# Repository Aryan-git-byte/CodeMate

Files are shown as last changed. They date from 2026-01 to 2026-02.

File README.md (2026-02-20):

# CodeMate - My Dev Macropad
hiii! this is my hackpad submission. built a 3x3 macropad to speed up my coding workflow

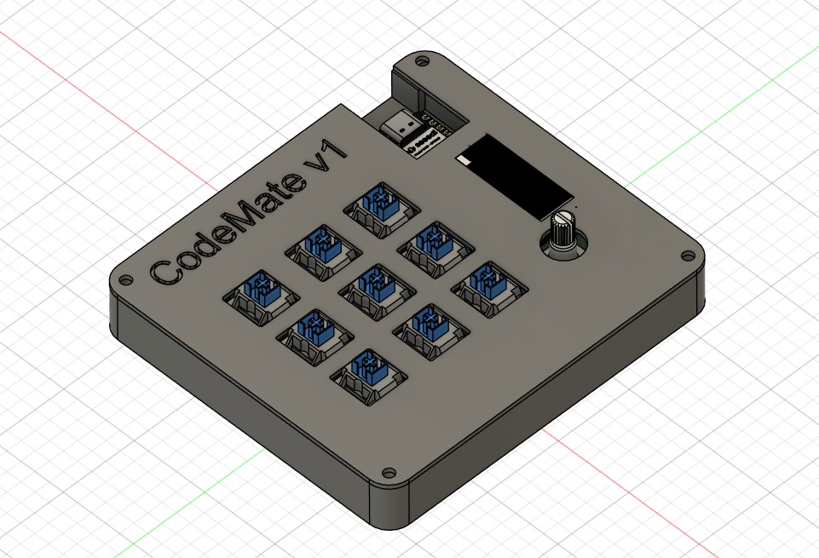
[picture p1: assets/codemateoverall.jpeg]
CodeMate Overall


## what it does
- 9 mechanical switches in a 3x3 grid for shortcuts and macros
- rotary encoder for volume control
- 0.91" OLED that shows which key i just pressed (flashes for 1.5sec then shows "ready")
- 6 RGB LEDs that breathe in warm amber and pulse when i hit keys
- runs on Arduino (not KMK anymore) so i can use TinyUSB

## PCB
heres what the electronics look like:

| Schematic | PCB |
|---|-----|
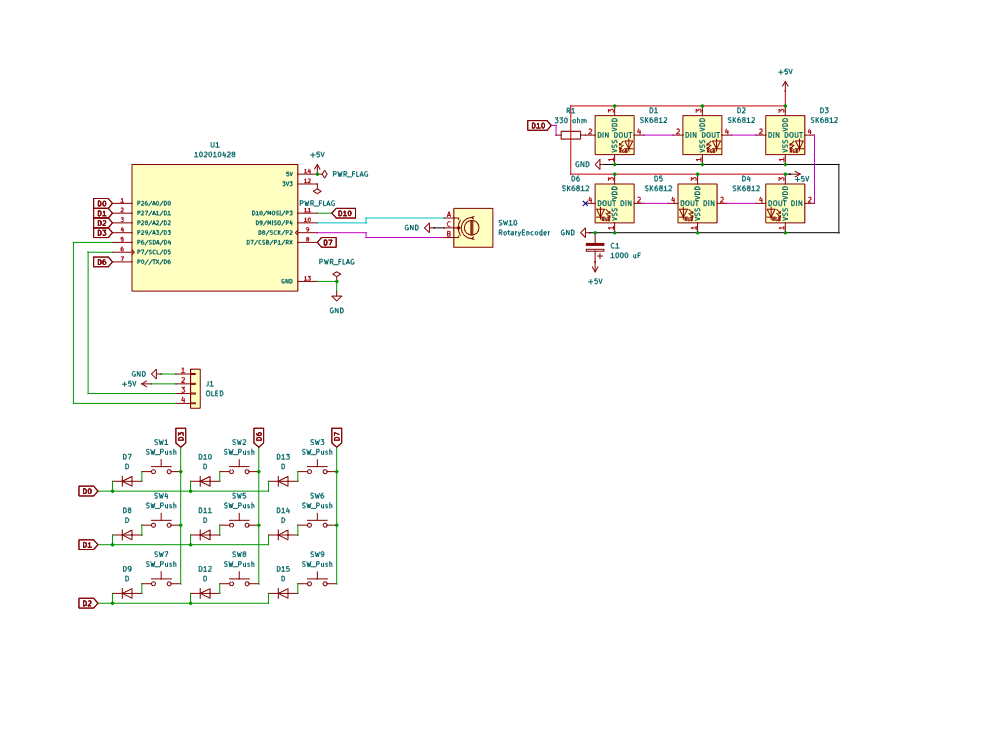
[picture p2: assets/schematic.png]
Schematic
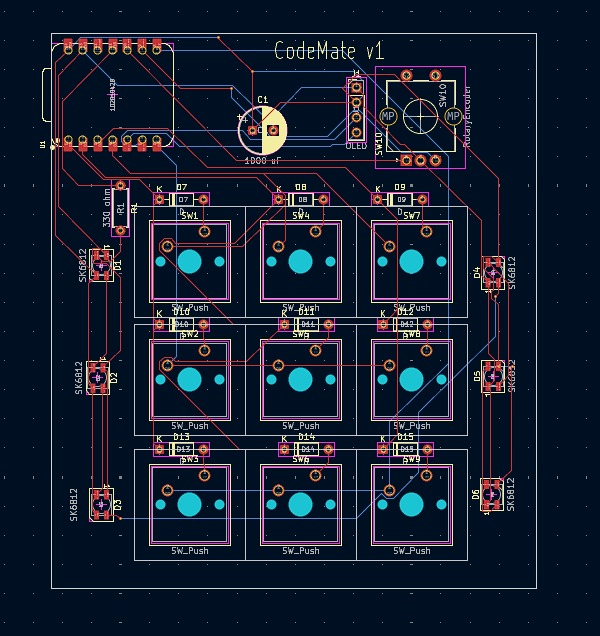
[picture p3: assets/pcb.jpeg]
PCB
|  |  |

took me a few tries to get the routing right but it works now

[x] I ran DRC and there are 0 errors but few silkscreen warnings

## Case
made in fusion360. fits everything together with M3 screws and heatset inserts

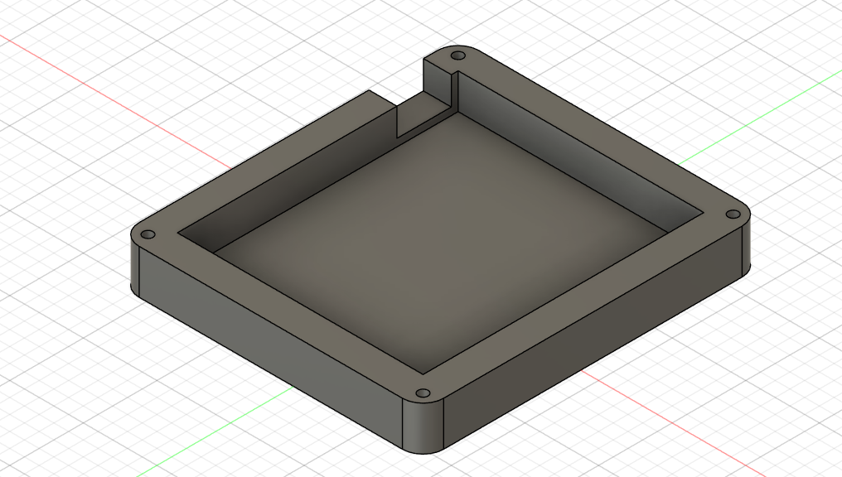
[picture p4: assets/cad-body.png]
CAD Model


along with the top:

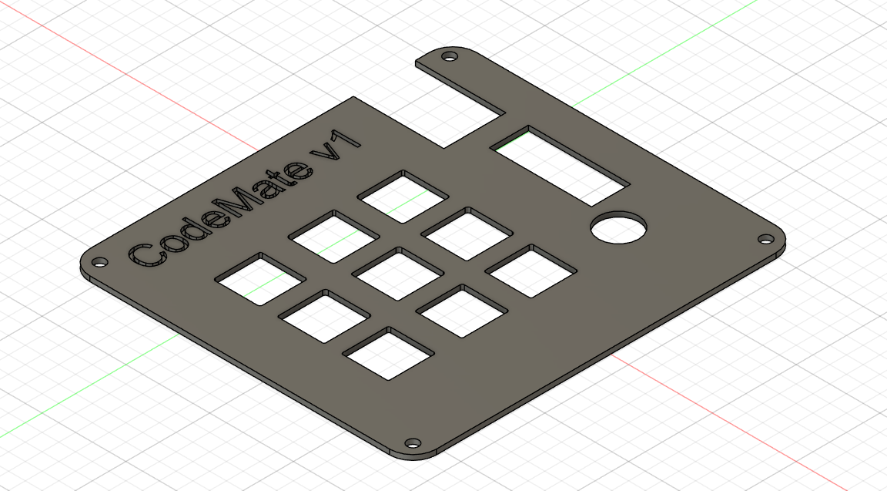
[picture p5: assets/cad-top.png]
CAD-Top


the switches poke through the top plate and the oled sits in a cutout. pretty clean imo

## Firmware
rewrote it in Arduino because i wanted better HID support. NO LAYERS anymore, just 9 coding shortcuts that i actually use:

**The Layout:**
```
Comment      | Format Code    | Duplicate Line
Run (F5)     | Terminal       | Close Tab
git status   | git commit     | git push
```

Encoder: Volume up/down (stays the same always)

### what each key does
- **Key 0:** Toggle comment (Ctrl+/)
- **Key 1:** Format code (Shift+Alt+F)
- **Key 2:** Duplicate line (Shift+Alt+Down)
- **Key 3:** Run code (F5)
- **Key 4:** Toggle terminal (Ctrl+`)
- **Key 5:** Close tab (Ctrl+W)
- **Key 6:** Opens terminal + runs `git status`
- **Key 7:** Opens terminal + types `git commit -m ""` with cursor inside quotes
- **Key 8:** Opens terminal + runs `git push`

git commands automatically open the VS Code terminal first (Ctrl+Shift+`) then type the command. super handy

### LED behavior
- **Normal:** slow breathing effect (10% to 40% brightness) in warm amber
- **When you press a key:** the LED near that key flashes bright then fades back to breathing
- **Color:** warm amber (255, 140, 0) because one of my LEDs has a dead blue channel lol

the oled shows which key i pressed for 1.5 seconds then goes back to showing "ready"

[x] no api keys or passwords in the code

## BOM
what you need to build this:
- 1x XIAO RP2040
- 9x Cherry MX switches  
- 9x 1N4148 diodes
- 6x SK6812 MINI-E LEDs (NOT WS2812B, different color order)
- 1x 0.91" SSD1306 OLED (128x32, I2C)
- 1x EC11 rotary encoder
- 1x 330Ω resistor (for LED data line - optional but recommended)
- 1x 1000µF capacitor (bulk cap for LEDs - optional but recommended)
- 4x M3x16mm screws
- 4x M3x5mmx4mm heatset inserts

## notes
this was fun to make! spent way too much time tweaking the firmware but learned a lot about Arduino HID and how SK6812 LEDs work differently from WS2812B.

switched from KMK to Arduino because i wanted proper keyboard+consumer HID support and the encoder was being weird in KMK. plus now i can do the breathing LED effect which looks way cooler than static colors

GG

# this is the prototype:

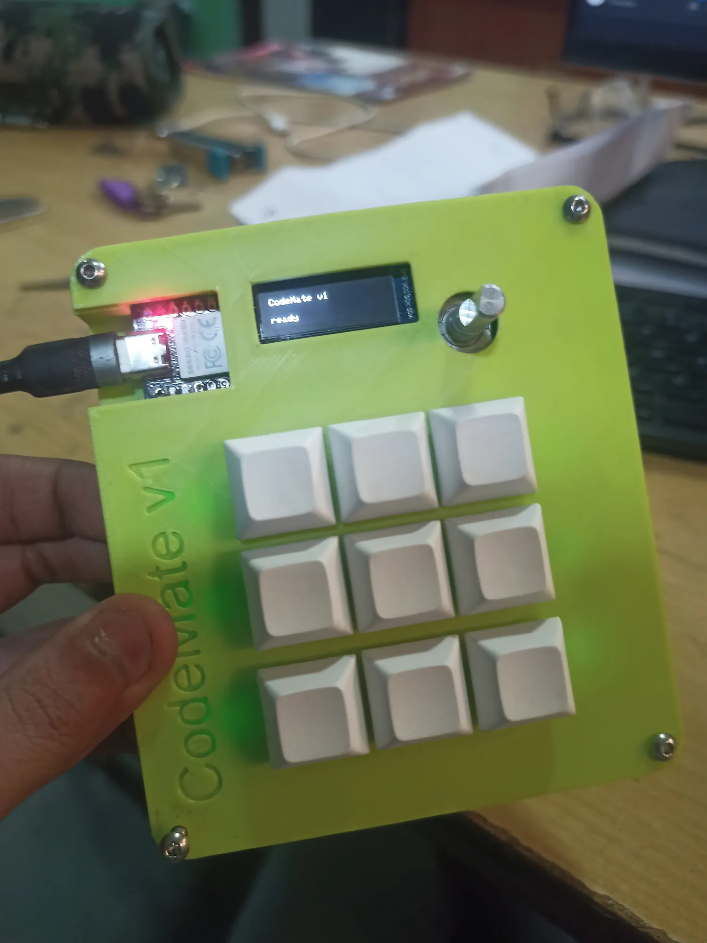
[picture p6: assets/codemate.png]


## and when buttons are pressed it looks like:
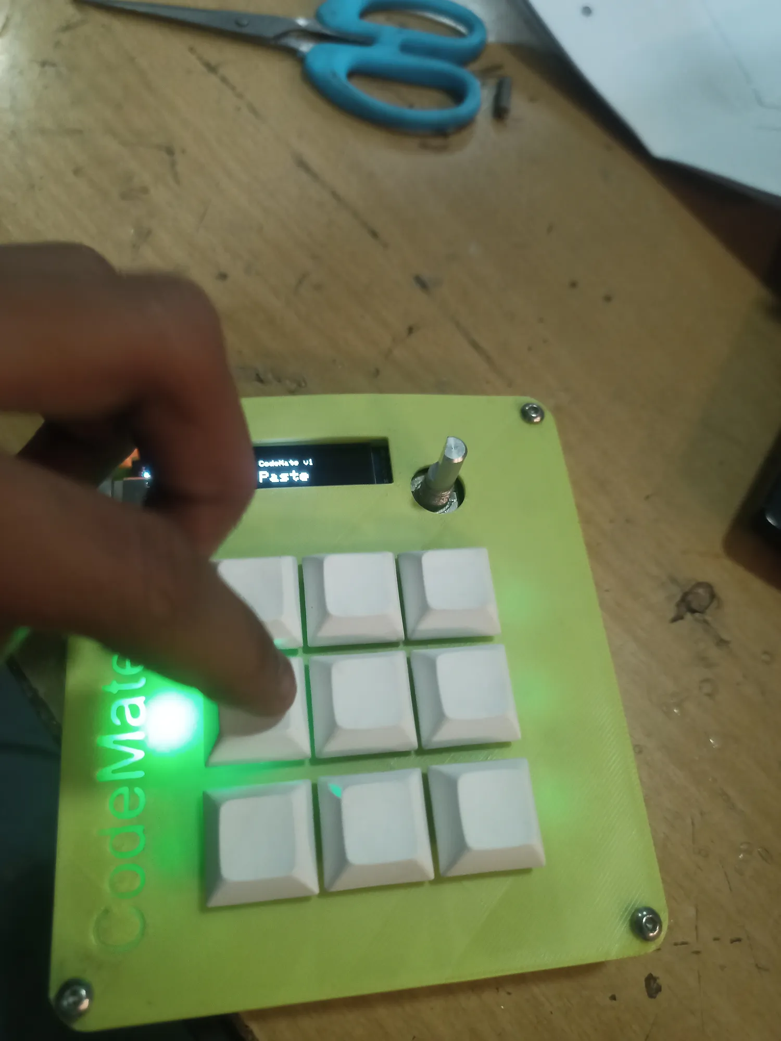
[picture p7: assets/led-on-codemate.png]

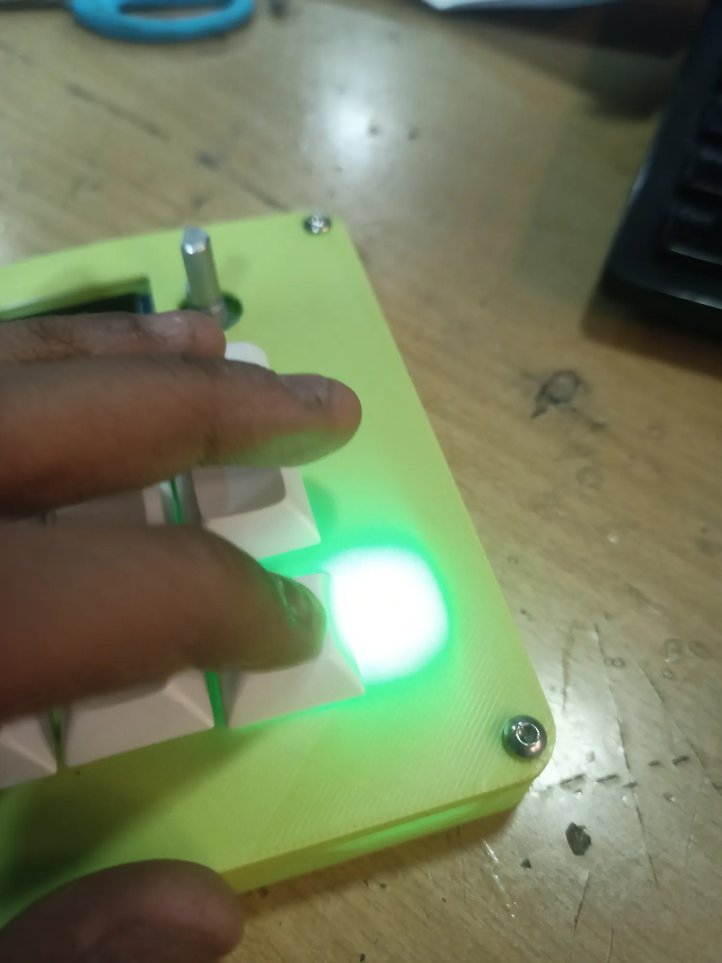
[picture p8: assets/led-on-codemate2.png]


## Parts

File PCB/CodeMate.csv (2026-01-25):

Reference | Qty | Value | DNP | Exclude from BOM | Exclude from Board | Footprint | Datasheet
C1 | 1 | 1000 uF |  |  |  | Capacitor_THT:CP_Radial_D8.0mm_P3.50mm | ~
D1,D2,D3,D4,D5,D6 | 6 | SK6812 |  |  |  | LED_SMD:LED_SK6812MINI_PLCC4_3.5x3.5mm_P1.75mm | https://cdn-shop.adafruit.com/product-files/1138/SK6812+LED+datasheet+.pdf
D7,D8,D9,D10,D11,D12,D13,D14,D15 | 9 | D |  |  |  | Diode_THT:D_DO-35_SOD27_P7.62mm_Horizontal | ~
J1 | 1 | OLED |  |  |  | Connector_PinHeader_2.54mm:PinHeader_1x04_P2.54mm_Vertical | ~
R1 | 1 | 330 ohm |  |  |  | Resistor_THT:R_Axial_DIN0207_L6.3mm_D2.5mm_P7.62mm_Horizontal | ~
SW1,SW2,SW3,SW4,SW5,SW6,SW7,SW8,SW9 | 9 | SW_Push |  |  |  | Button_Switch_Keyboard:SW_Cherry_MX_1.00u_PCB | ~
SW10 | 1 | RotaryEncoder |  |  |  | Rotary_Encoder:RotaryEncoder_Alps_EC11E-Switch_Vertical_H20mm_CircularMountingHoles | ~
U1 | 1 | 102010428 |  |  |  | Seeed Studio XIAO Series Library:XIAO-RP2040-DIP

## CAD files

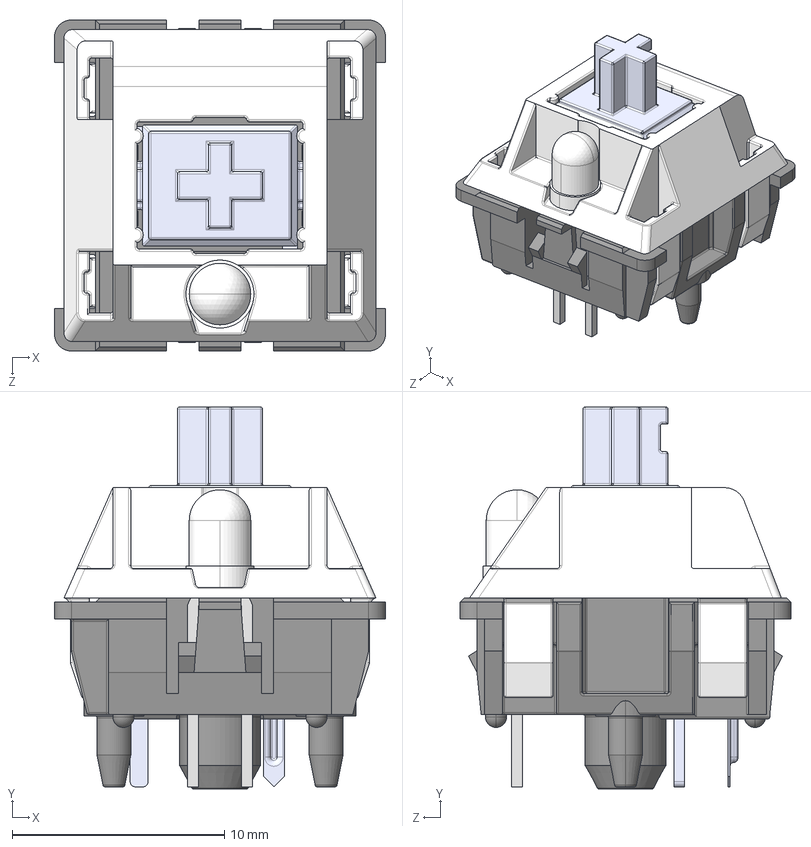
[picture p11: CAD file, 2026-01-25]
CAD/3D-models-of-parts/cherry-mx-red-switch-1.snapshot.3/Cherry MX.STEP
15.6 x 18.0 x 15.6 mm
Bottom
Pulsador
Top
Pieza5^Cherry MX
Pin1
Pin2
Led 3mm_trans

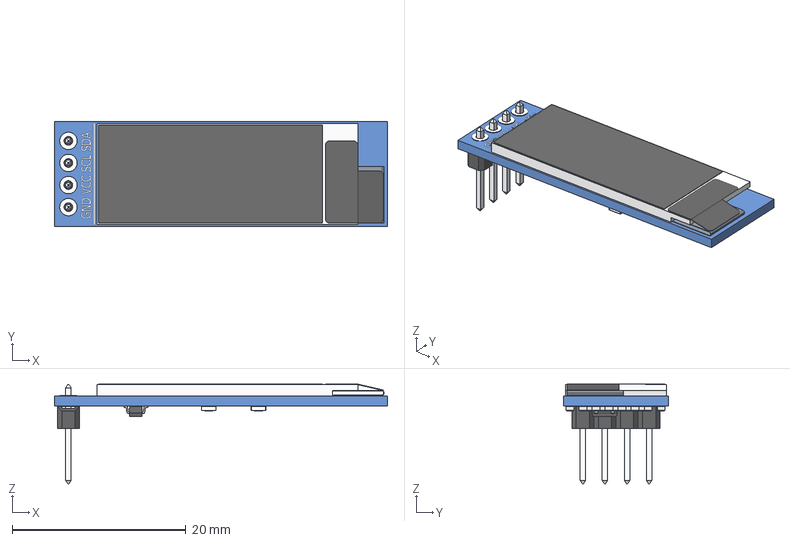
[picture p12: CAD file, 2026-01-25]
CAD/3D-models-of-parts/oled-0-91-128x32-1.snapshot.1/OLED_0.91_128x32.stp
38.3 x 12.1 x 11.5 mm
OLED_0.91_128x32
Pin Header 4 x 1 TH 2.54mm Pitch
RESC-0603 x 13
2SD0601A

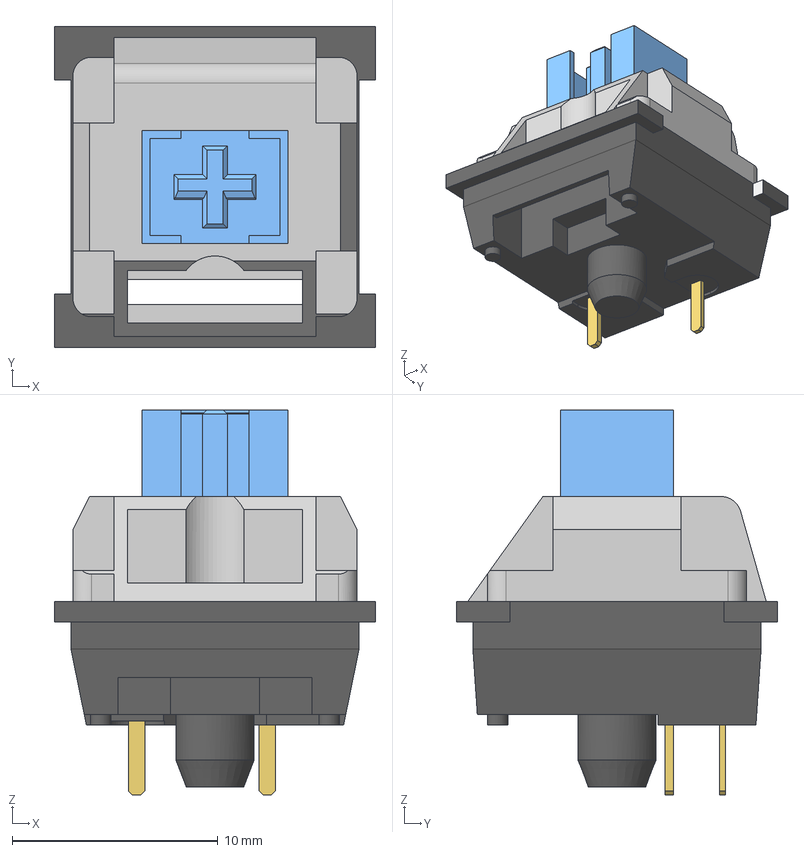
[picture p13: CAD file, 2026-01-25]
CAD/3D-models-of-parts/REDragon-MX-ZT02.stp
15.6 x 15.6 x 18.7 mm
Button
Pins

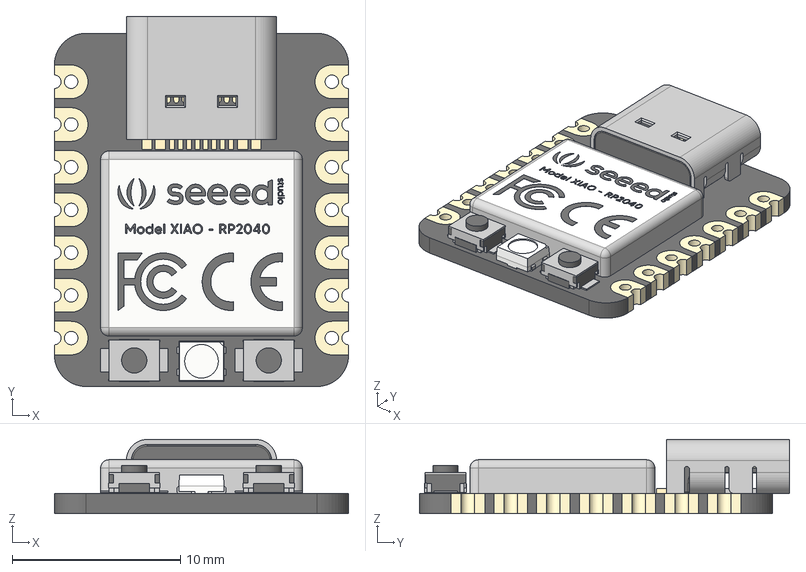
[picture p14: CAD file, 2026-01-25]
CAD/3D-models-of-parts/Seed-studio-xiao-rp2040/Seeed Studio XIAO RP2040 v26.step
17.5 x 22.0 x 4.40 mm
type-c v2
smd_button v3
DOUT
DIN
VSS
VDD
smd_button v3(Mirror)

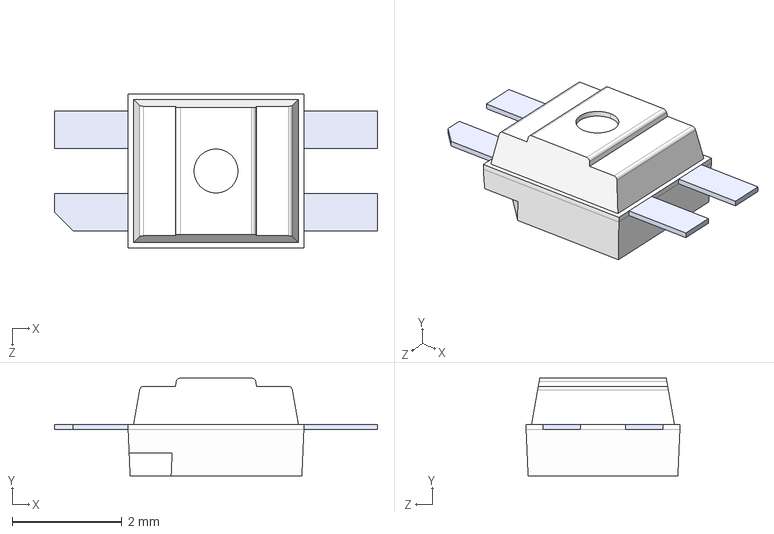
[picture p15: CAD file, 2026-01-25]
CAD/3D-models-of-parts/SK6812/SK6812-E--3DModel-STEP-418109.STEP
5.88 x 1.78 x 2.80 mm

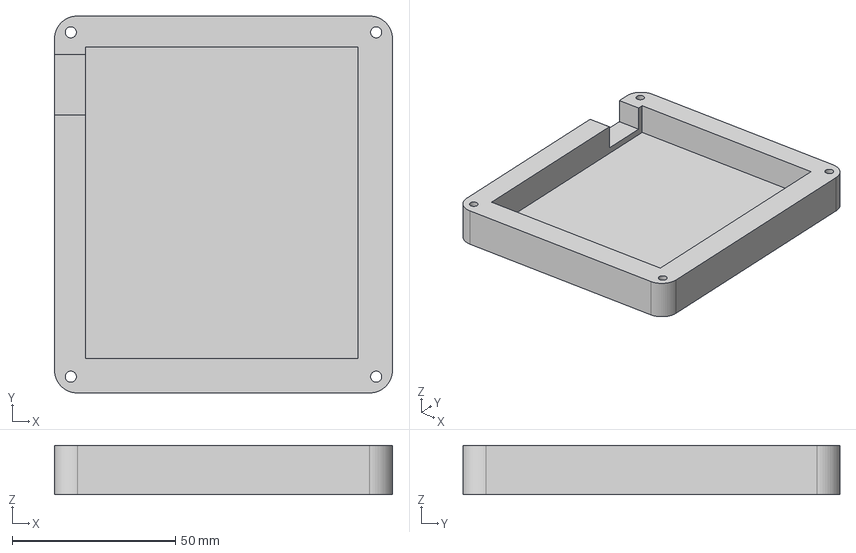
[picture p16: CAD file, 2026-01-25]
CAD/CodeMate-Body.step
103.4 x 115.3 x 15.0 mm

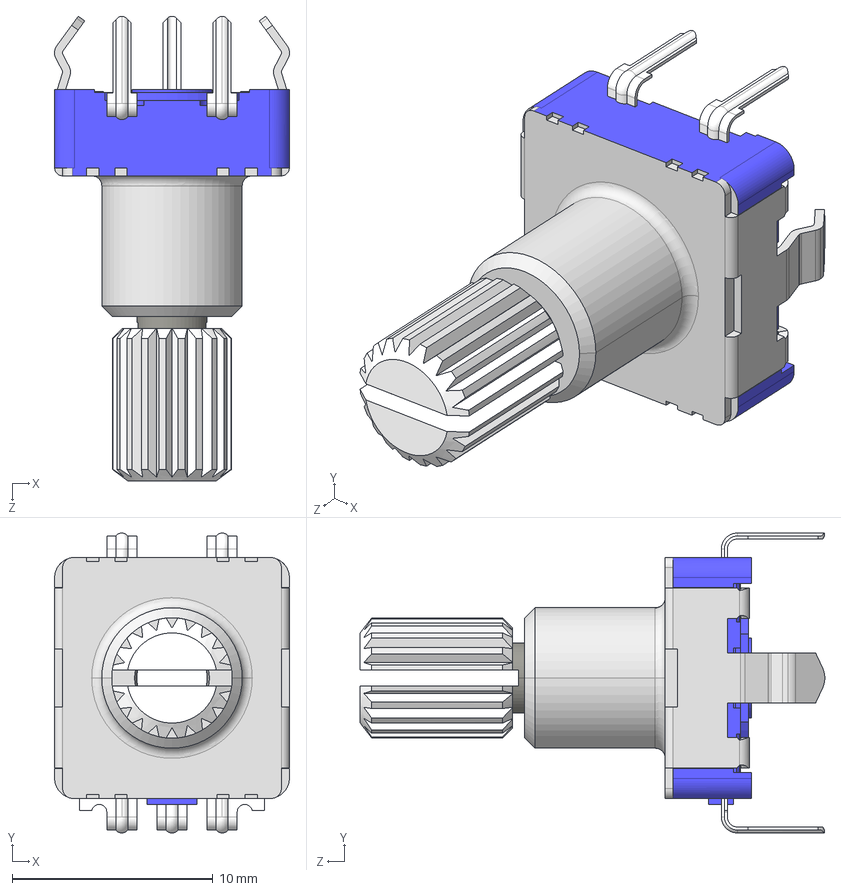
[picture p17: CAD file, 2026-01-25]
CAD/3D-models-of-parts/EC11 Rotary Encoder Dode Switch-15mm .STEP
11.7 x 15.0 x 23.2 mm

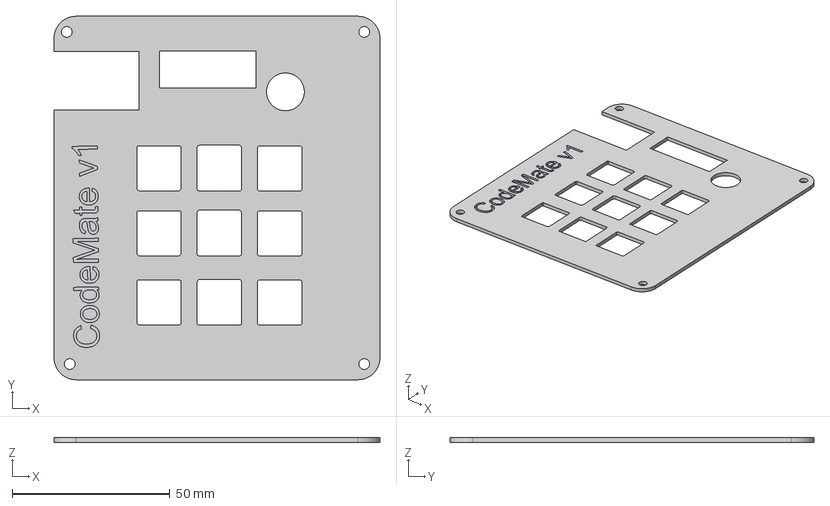
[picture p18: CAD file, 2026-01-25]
CAD/Codemate top.step
103.4 x 115.3 x 1.50 mm

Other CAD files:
CAD/3D-models-of-parts/Seed-studio-xiao-rp2040/Seeed Studio XIAO RP2040 v26.f3d
CAD/3D-models-of-parts/Seed-studio-xiao-rp2040/Seeed Studio XIAO RP2040 v26.iges

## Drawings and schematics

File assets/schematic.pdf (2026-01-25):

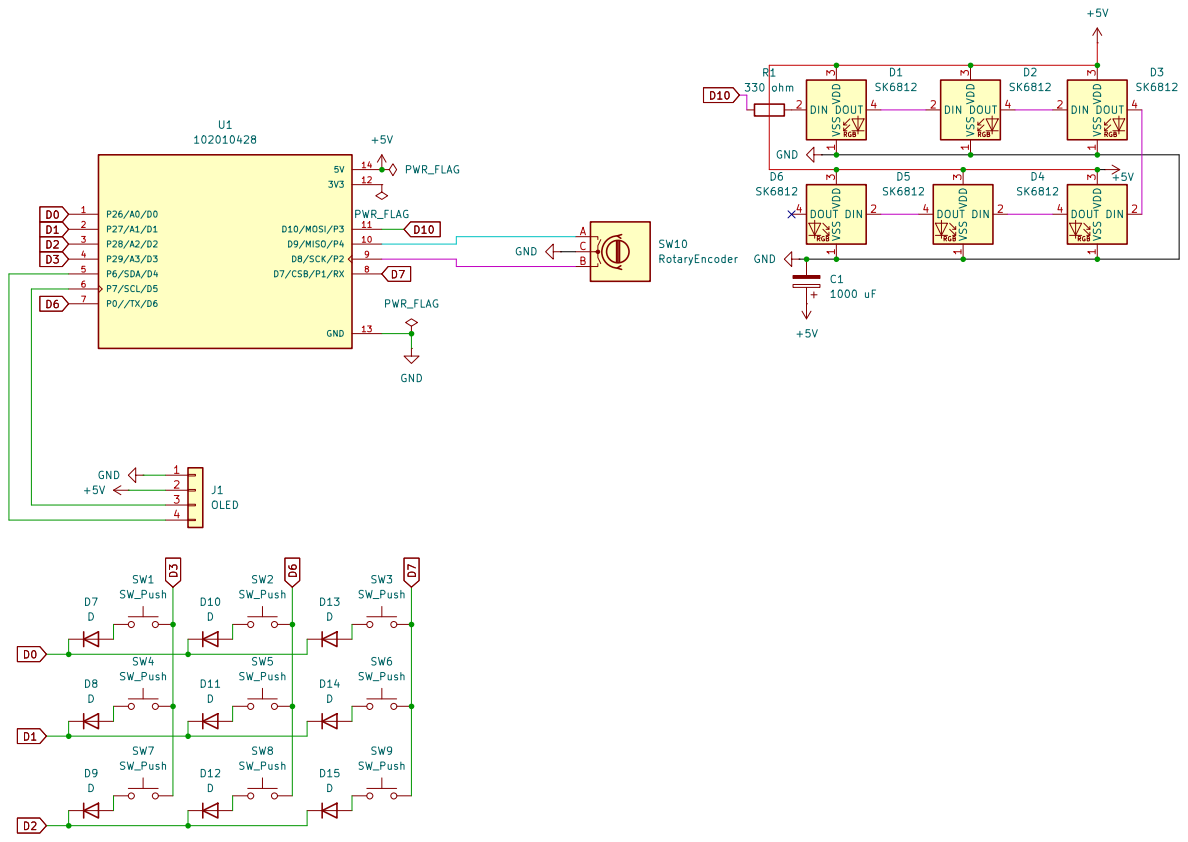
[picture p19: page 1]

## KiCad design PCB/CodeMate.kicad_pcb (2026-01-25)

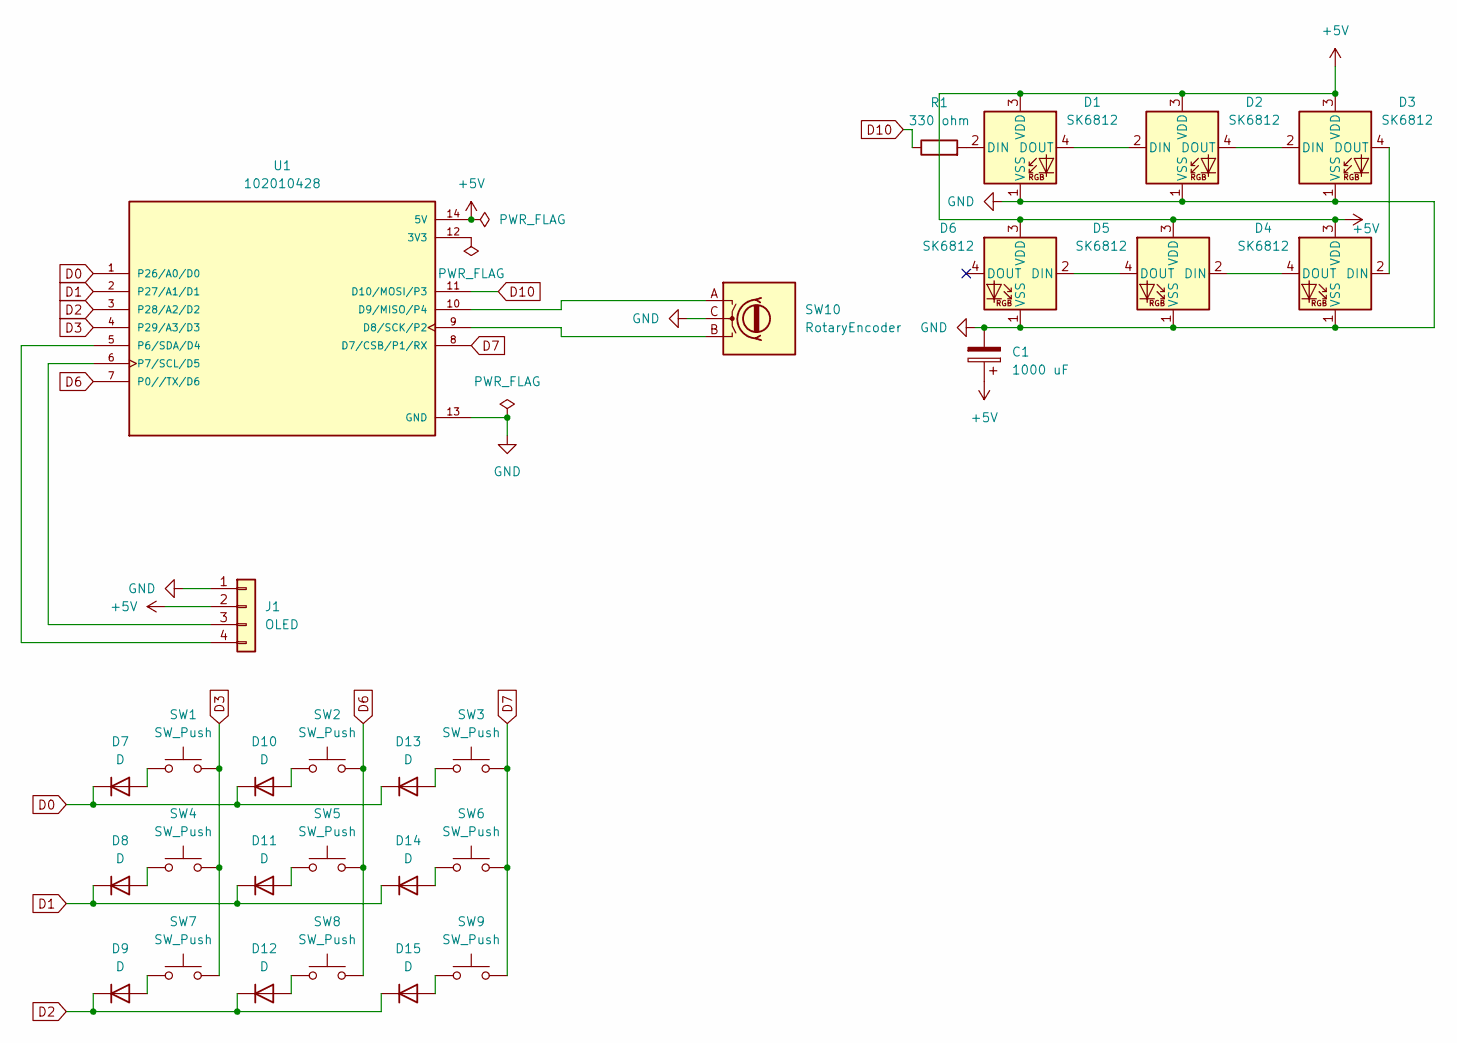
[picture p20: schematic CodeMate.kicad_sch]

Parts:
C1: 1000 uF; CP_Radial_D8.0mm_P3.50mm
D1, D2, D3, D4, D5, D6: SK6812; LED_SK6812MINI_PLCC4_3.5x3.5mm_P1.75mm
D7, D8, D9, D10, D11, D12, D13, D14, D15: D; D_DO-35_SOD27_P7.62mm_Horizontal
J1: OLED; PinHeader_1x04_P2.54mm_Vertical
R1: 330 ohm; R_Axial_DIN0207_L6.3mm_D2.5mm_P7.62mm_Horizontal
SW1, SW2, SW3, SW4, SW5, SW6, SW7, SW8, SW9: SW_Push; SW_Cherry_MX_1.00u_PCB
SW10: RotaryEncoder; RotaryEncoder_Alps_EC11E-Switch_Vertical_H20mm_CircularMoun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
U1: 102010428; XIAO-RP2040-DIP; PARTREV 1.3

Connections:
+5V: C1.1, D1.3 (VDD), D2.3 (VDD), D3.3 (VDD), D4.3 (VDD), D5.3 (VDD), D6.3 (VDD), J1.2, U1.14 (5V)
D0: D7.1 (K), D10.1 (K), D13.1 (K), U1.1 (P26/A0/D0)
D1: D8.1 (K), D11.1 (K), D14.1 (K), U1.2 (P27/A1/D1)
D2: D9.1 (K), D12.1 (K), D15.1 (K), U1.3 (P28/A2/D2)
D3: SW1.2, SW4.2, SW7.2, U1.4 (P29/A3/D3)
D6: SW2.2, SW5.2, SW8.2, U1.7 (P0//TX/D6)
D7: SW3.2, SW6.2, SW9.2, U1.8 (D7/CSB/P1/RX)
D10: R1.1, U1.11 (D10/MOSI/P3)
GND: C1.2, D1.1 (VSS), D2.1 (VSS), D3.1 (VSS), D4.1 (VSS), D5.1 (VSS), D6.1 (VSS), J1.1, SW10.C, U1.13 (GND)
unnamed: D1.2 (DIN), R1.2
unnamed: D1.4 (DOUT), D2.2 (DIN)
unnamed: D2.4 (DOUT), D3.2 (DIN)
unnamed: D3.4 (DOUT), D4.2 (DIN)
unnamed: D4.4 (DOUT), D5.2 (DIN)
unnamed: D5.4 (DOUT), D6.2 (DIN)
unnamed: D7.2 (A), SW1.1
unnamed: D8.2 (A), SW4.1
unnamed: D9.2 (A), SW7.1
unnamed: D10.2 (A), SW2.1
unnamed: D11.2 (A), SW5.1
unnamed: D12.2 (A), SW8.1
unnamed: D13.2 (A), SW3.1
unnamed: D14.2 (A), SW6.1
unnamed: D15.2 (A), SW9.1
unnamed: J1.3, U1.6 (P7/SCL/D5)
unnamed: J1.4, U1.5 (P6/SDA/D4)
unnamed: SW10.B, U1.9 (D8/SCK/P2)
unnamed: SW10.A, U1.10 (D9/MISO/P4)

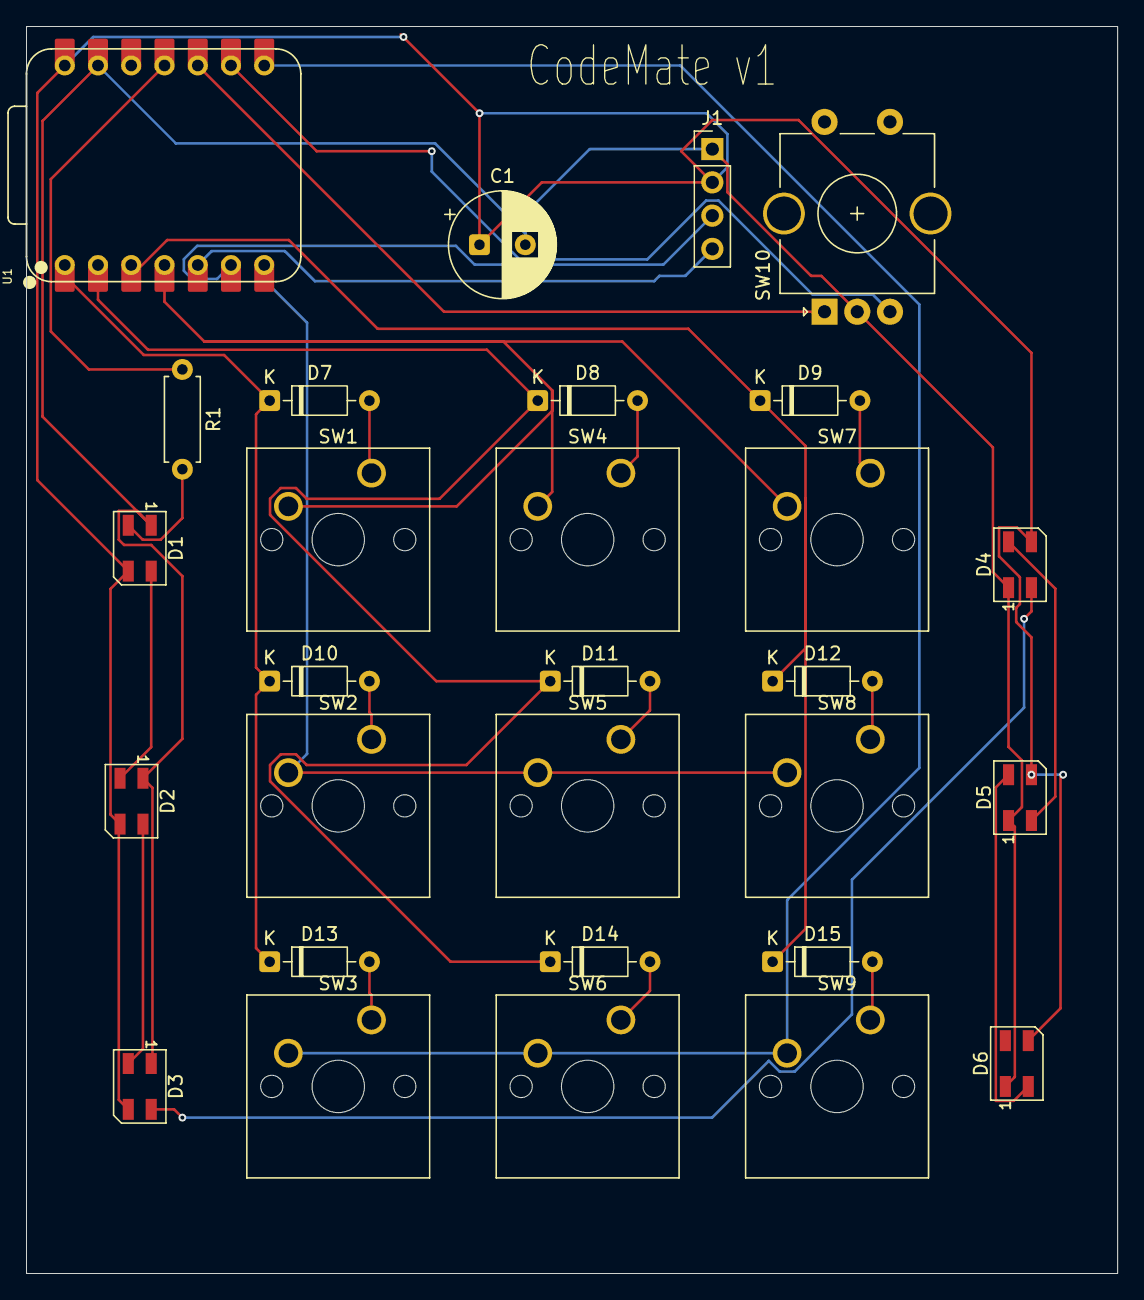
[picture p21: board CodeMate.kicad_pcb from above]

Board: 2 copper layers, 83.3 x 95.2 mm, 29 parts (0 on the bottom side), 28 nets.

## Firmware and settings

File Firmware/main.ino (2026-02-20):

/**
 * Codemate v1 - Macropad Firmware
 * Target: Seeed XIAO RP2040
 *
 * Hardware:
 *   - 3x3 key matrix (rows: D0/D1/D2, cols: D3/D6/D7), COL2ROW wiring
 *   - Rotary encoder (A: D8, B: D9) -> Volume up/down
 *   - 6x SK6812 MINI-E RGB LEDs chained on D10
 *   - SSD1306 OLED 128x32 via I2C @ 0x3C (optional)
 *
 * Key layout (coding-focused):
 *   [0] Comment (Ctrl+/)       [1] Uncomment (Ctrl+Shift+/) [2] Block Comment (Ctrl+Shift+A)
 *   [3] Run (F5)               [4] Debug (Shift+F5)          [5] Stop (Shift+F5)
 *   [6] git status + Enter     [7] git commit -m ""          [8] git push + Enter
 *
 * Encoder: CW = Vol+,  CCW = Vol-
 *
 * Board package: "Raspberry Pi Pico/RP2040" by Earle Philhower v5.5.0+
 *   Board:     Seeed XIAO RP2040
 *   USB Stack: Adafruit TinyUSB  <- must be set in Tools menu
 *
 * Libraries needed (Arduino Library Manager):
 *   - Adafruit NeoPixel
 *   - Adafruit TinyUSB Library   <- if not already present
 *   - Adafruit SSD1306 + Adafruit GFX Library  (only if using OLED)
 */

#include <Arduino.h>
#include <Adafruit_TinyUSB.h>
#include <Adafruit_NeoPixel.h>

// ── Optional OLED ─────────────────────────────────────────────────────────────
#define USE_OLED 1   // set to 0 if OLED not soldered
#if USE_OLED
  #include <Wire.h>
  #include <Adafruit_SSD1306.h>
  #define OLED_ADDR 0x3C
  Adafruit_SSD1306 oled(128, 32, &Wire, -1);
  bool oledReady = false;
#endif

// ── USB HID — keyboard ────────────────────────────────────────────────────────
// Full keyboard HID descriptor
uint8_t const descKbd[] = { TUD_HID_REPORT_DESC_KEYBOARD() };
Adafruit_USBD_HID usbKbd(descKbd, sizeof(descKbd), HID_ITF_PROTOCOL_KEYBOARD, 2, false);

// ── USB HID — consumer (media keys) ──────────────────────────────────────────
uint8_t const descMedia[] = { TUD_HID_REPORT_DESC_CONSUMER() };
Adafruit_USBD_HID usbMedia(descMedia, sizeof(descMedia), HID_ITF_PROTOCOL_NONE, 2, false);

// ── Pins ──────────────────────────────────────────────────────────────────────
const uint8_t ROW_PINS[3] = { D0, D1, D2 };
const uint8_t COL_PINS[3] = { D3, D6, D7 };
const uint8_t ENC_A       = D8;
const uint8_t ENC_B       = D9;

// ── RGB ───────────────────────────────────────────────────────────────────────
#define LED_PIN   D10
#define LED_COUNT 6
// SK6812 MINI-E uses RGB color order (not GRB like WS2812B)
Adafruit_NeoPixel strip(LED_COUNT, LED_PIN, NEO_RGB + NEO_KHZ800);

// ── Debounce ──────────────────────────────────────────────────────────────────
#define DEBOUNCE_MS 12
bool     keyState[3][3]   = {};
bool     rawState[3][3]   = {};
uint32_t lastChange[3][3] = {};

// ── Encoder — quadrature state machine ───────────────────────────────────────
uint8_t encState = 0;
int8_t  encAccum = 0;
const int8_t ENC_TABLE[16] = {
    0, -1,  1,  0,
    1,  0,  0, -1,
   -1,  0,  0,  1,
    0,  1, -1,  0
};

// ── RGB animation — breathing + keypress pulse ───────────────────────────────
float    breathPhase       = 0.0;      // breathing animation phase
int      activeLED         = -1;       // which LED to pulse (-1 = all breathe)
uint32_t ledPulseStart     = 0;        // when the LED pulse started
uint32_t lastFrameTime     = 0;        // last time we updated LEDs
#define  LED_PULSE_MS      400         // pulse duration (ms)
#define  FRAME_DELAY_MS    30          // ~33fps, prevents flickering
// Warm amber color (no blue - LED #0 has dead blue channel)
#define  BASE_R            255
#define  BASE_G            140
#define  BASE_B            0

// Map key positions to LED indices (customize based on your physical layout)
// Keys 0-8 correspond to your 3x3 grid, LEDs 0-5 are your strip
const int8_t KEY_TO_LED[9] = {
  0,  // Key 0 (Copy)       → LED 0
  1,  // Key 1 (Paste)      → LED 1
  2,  // Key 2 (Undo)       → LED 2
  2,  // Key 3 (Save)       → LED 2
  3,  // Key 4 (Play/Pause) → LED 3
  4,  // Key 5 (Mute)       → LED 4
  4,  // Key 6 (Next)       → LED 4
  5,  // Key 7 (Prev)       → LED 5
  5   // Key 8 (Screenshot) → LED 5
};

// ── OLED ──────────────────────────────────────────────────────────────────────
#if USE_OLED
const char* KEY_LABELS[9] = {
  "Comment", "Uncmmnt", "Block",
  "Run",     "Debug",   "Stop",
  "git st",  "commit",  "push"
};
bool     oledDirty      = false;
int      oledKeyIdx     = -1;
uint32_t oledKeyShownAt = 0;
#define  OLED_KEY_MS    1500

void drawOLED(int keyIdx) {
  if (!oledReady) return;
  oled.clearDisplay();
  oled.setTextColor(SSD1306_WHITE);
  oled.setTextSize(1);
  oled.setCursor(0, 0);
  oled.print("CodeMate v1");
  if (keyIdx >= 0) {
    oled.setTextSize(2);
    oled.setCursor(0, 16);
    oled.print(KEY_LABELS[keyIdx]);
  } else {
    oled.setTextSize(1);
    oled.setCursor(0, 20);
    oled.print("ready");
  }
  oled.display();
}
#endif

// ── HID helpers ───────────────────────────────────────────────────────────────
void sendKey(uint8_t modifier, uint8_t keycode) {
  uint8_t keycodes[6] = { keycode, 0, 0, 0, 0, 0 };
  usbKbd.keyboardReport(0, modifier, keycodes);
  delay(15);
  uint8_t empty[6] = {};
  usbKbd.keyboardReport(0, 0, empty);
  delay(5);
}

void sendConsumer(uint16_t usage) {
  usbMedia.sendReport16(0, usage);
  delay(15);
  usbMedia.sendReport16(0, 0);
  delay(5);
}

void sendString(const char* str) {
  // Type a string character by character
  while (*str) {
    char c = *str++;
    uint8_t key = 0, mod = 0;
    
    // Map ASCII to HID keycodes
    if (c >= 'a' && c <= 'z') {
      key = HID_KEY_A + (c - 'a');
    } else if (c >= 'A' && c <= 'Z') {
      key = HID_KEY_A + (c - 'A');
      mod = KEYBOARD_MODIFIER_LEFTSHIFT;
    } else if (c >= '1' && c <= '9') {
      key = HID_KEY_1 + (c - '1');
    } else if (c == '0') {
      key = HID_KEY_0;
    } else {
      switch (c) {
        case ' ':  key = HID_KEY_SPACE;       break;
        case '-':  key = HID_KEY_MINUS;       break;
        case '"':  key = HID_KEY_APOSTROPHE;
                   mod = KEYBOARD_MODIFIER_LEFTSHIFT; break;
        default:   continue;
      }
    }
    sendKey(mod, key);
    delay(5);
  }
}

void ctrlKey(uint8_t keycode) {
  sendKey(KEYBOARD_MODIFIER_LEFTCTRL, keycode);
}

void ctrlShiftKey(uint8_t keycode) {
  sendKey(KEYBOARD_MODIFIER_LEFTCTRL | KEYBOARD_MODIFIER_LEFTSHIFT, keycode);
}

void winShiftKey(uint8_t keycode) {
  sendKey(KEYBOARD_MODIFIER_LEFTGUI | KEYBOARD_MODIFIER_LEFTSHIFT, keycode);
}

// ── Key press dispatcher ──────────────────────────────────────────────────────
void handleKeyPress(uint8_t row, uint8_t col) {
  uint8_t idx = row * 3 + col;

  // Trigger LED pulse for this key's mapped LED
  activeLED      = KEY_TO_LED[idx];
  ledPulseStart  = millis();

#if USE_OLED
  oledKeyIdx     = idx;
  oledKeyShownAt = millis();
  oledDirty      = true;
  drawOLED(idx);
#endif

  switch (idx) {
    case 0: ctrlKey(HID_KEY_SLASH);                      break; // Toggle comment (Ctrl+/)
    case 1: ctrlShiftKey(HID_KEY_SLASH);                 break; // Uncomment (Ctrl+Shift+/)
    case 2: 
      // Block comment: Ctrl+Shift+A (VS Code) or Shift+Alt+A
      ctrlShiftKey(HID_KEY_A);
      break;
    case 3: sendKey(0, HID_KEY_F5);                      break; // Run (F5)
    case 4: sendKey(KEYBOARD_MODIFIER_LEFTSHIFT, HID_KEY_F5); break; // Debug (Shift+F5)
    case 5: sendKey(KEYBOARD_MODIFIER_LEFTSHIFT, HID_KEY_F5); break; // Stop (Shift+F5)
    case 6: 
      // git status: open terminal, wait, type command
      ctrlShiftKey(HID_KEY_GRAVE);  // Ctrl+Shift+` to toggle terminal
      delay(200);                    // wait for terminal to open
      sendString("git status");
      sendKey(0, HID_KEY_ENTER);
      break;
    case 7:
      // git commit: open terminal, wait, type command with cursor inside quotes
      ctrlShiftKey(HID_KEY_GRAVE);  // Ctrl+Shift+` to toggle terminal
      delay(200);
      sendString("git commit -m \"\"");
      sendKey(0, HID_KEY_ARROW_LEFT);
      break;
    case 8:
      // git push: open terminal, wait, type command
      ctrlShiftKey(HID_KEY_GRAVE);  // Ctrl+Shift+` to toggle terminal
      delay(200);
      sendString("git push");
      sendKey(0, HID_KEY_ENTER);
      break;
  }
}

// ── Encoder handler ───────────────────────────────────────────────────────────
void handleEncoder(int dir) {
  if (dir > 0) sendConsumer(HID_USAGE_CONSUMER_VOLUME_INCREMENT);
  else         sendConsumer(HID_USAGE_CONSUMER_VOLUME_DECREMENT);
}

// ── Setup ─────────────────────────────────────────────────────────────────────
void setup() {
  // Matrix rows
  for (int r = 0; r < 3; r++) {
    pinMode(ROW_PINS[r], OUTPUT);
    digitalWrite(ROW_PINS[r], HIGH);
  }
  // Matrix cols
  for (int c = 0; c < 3; c++) {
    pinMode(COL_PINS[c], INPUT_PULLUP);
  }

  // Encoder
  pinMode(ENC_A, INPUT_PULLUP);
  pinMode(ENC_B, INPUT_PULLUP);
  encState = (digitalRead(ENC_A) << 1) | digitalRead(ENC_B);

  // RGB — breathing + pulse effect
  strip.begin();
  strip.show();

  // USB HID — begin both interfaces
  usbKbd.begin();
  usbMedia.begin();

  // Wait for USB host to enumerate
  while (!TinyUSBDevice.mounted()) delay(1);
  delay(100); // brief settle after mount

#if USE_OLED
  Wire.begin();
  oledReady = oled.begin(SSD1306_SWITCHCAPVCC, OLED_ADDR);
  if (oledReady) {
    oled.setRotation(2);   // flip 180 degrees — fixes upside-down mounting
    oled.clearDisplay();
    oled.display();
    drawOLED(-1);
  }
#endif
}

// ── Main loop ─────────────────────────────────────────────────────────────────
void loop() {
  uint32_t now = millis();

  // ── Matrix scan ───────────────────────────────────────────────────────────
  for (int r = 0; r < 3; r++) {
    digitalWrite(ROW_PINS[r], LOW);
    delayMicroseconds(10);

    for (int c = 0; c < 3; c++) {
      bool pressed = (digitalRead(COL_PINS[c]) == LOW);

      if (pressed != rawState[r][c]) {
        rawState[r][c]   = pressed;
        lastChange[r][c] = now;
      }
      if ((now - lastChange[r][c]) >= DEBOUNCE_MS && pressed != keyState[r][c]) {
        keyState[r][c] = pressed;
        if (pressed) handleKeyPress(r, c);
      }
    }

    digitalWrite(ROW_PINS[r], HIGH);
  }

  // ── Encoder ───────────────────────────────────────────────────────────────
  uint8_t cur = (digitalRead(ENC_A) << 1) | digitalRead(ENC_B);
  if (cur != encState) {
    uint8_t tableIdx = (encState << 2) | cur;
    encAccum += ENC_TABLE[tableIdx];
    encState  = cur;
    if (encAccum >= 4)  { encAccum = 0; handleEncoder( 1); }
    if (encAccum <= -4) { encAccum = 0; handleEncoder(-1); }
  }

  // ── OLED timeout ─────────────────────────────────────────────────────────
#if USE_OLED
  if (oledDirty && (now - oledKeyShownAt) >= OLED_KEY_MS) {
    oledDirty  = false;
    oledKeyIdx = -1;
    drawOLED(-1);
  }
#endif

  // ── RGB breathing + per-key pulse ────────────────────────────────────────
  // Frame rate limiting - only update every FRAME_DELAY_MS to prevent flicker
  if ((now - lastFrameTime) < FRAME_DELAY_MS) {
    return;  // skip this frame
  }
  lastFrameTime = now;
  
  // Update breathing phase
  breathPhase += 0.03;
  float breathLevel = (sin(breathPhase) + 1.0) / 2.0;  // 0.0 to 1.0
  float breathBrightness = 0.1 + (breathLevel * 0.3);  // 10% to 40%
  
  // Check if pulse is still active
  bool pulseActive = (activeLED >= 0) && ((now - ledPulseStart) < LED_PULSE_MS);
  
  // Update each LED
  for (int i = 0; i < LED_COUNT; i++) {
    float brightness;
    
    if (pulseActive && i == activeLED) {
      // This LED is pulsing - flash then fade back to breath
      uint32_t elapsed = now - ledPulseStart;
      float progress = (float)elapsed / LED_PULSE_MS;
      brightness = 1.0 - (progress * (1.0 - breathBrightness));  // fade from 100% to breath
    } else {
      // Normal breathing
      brightness = breathBrightness;
    }
    
    uint8_t r = BASE_R * brightness;
    uint8_t g = BASE_G * brightness;
    uint8_t b = BASE_B * brightness;
    
    strip.setPixelColor(i, strip.gamma32(strip.Color(r, g, b)));
  }
  
  strip.show();
  
  // Clear active LED when pulse completes
  if (!pulseActive && activeLED >= 0) {
    activeLED = -1;
  }
}
